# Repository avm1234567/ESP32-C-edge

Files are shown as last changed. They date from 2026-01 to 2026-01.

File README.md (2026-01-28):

<h1 align="center">ESP32-C-edge</h1>

This project is a custom-designed ESP32-S3 development board created by me, featuring a USB Type-C edge connector directly integrated into the PCB. The board is intended to be compact, easy to manufacture, and convenient for prototyping without requiring a separate USB connector footprint.

---

## Overview

- MCU: **ESP32-S3**
- USB Interface: **USB Type-C via PCB edge connector**
- Purpose:
  - Minimal and compact ESP32-S3 dev board  
  - Direct USB connection without soldered connector  
  - Useful for experiments, prototypes, and small form-factor designs  
  - Learning project for PCB edge connectors and USB-C implementation  

---

## Features

- USB Type-C edge connector
- On-board ESP32-S3
- There are 3 USB Type-C in this design
    - Two on the right side are connected to a USB-TTL (CP2102).
    - One on the left is connected to D+ and D- pins of ESP32-S3.

---

## Results
| 3D-Viewer | Actual |
| --- | --- |
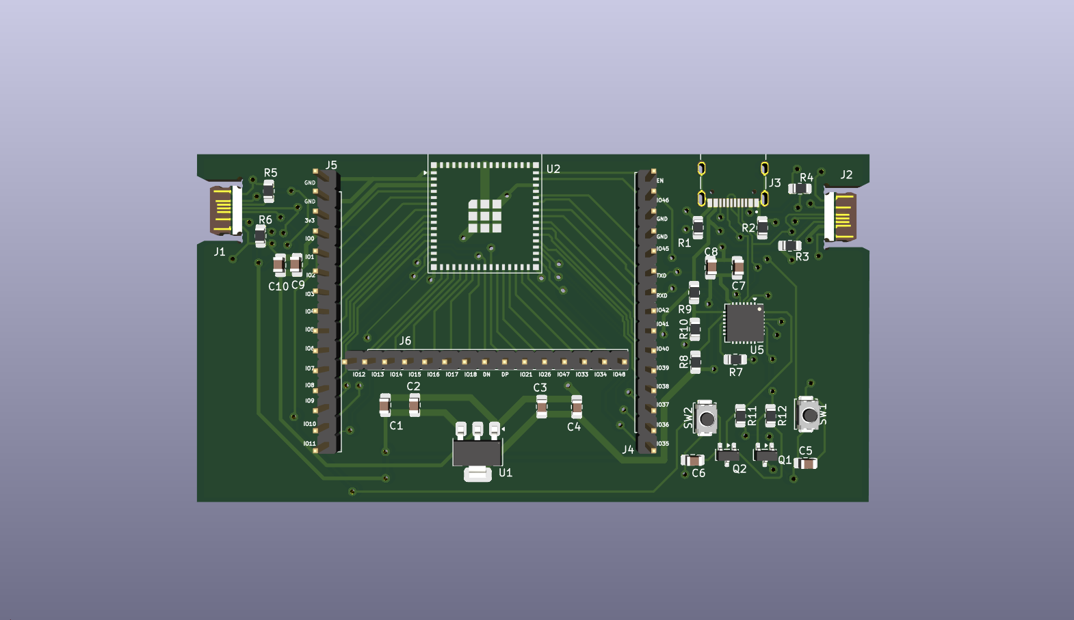
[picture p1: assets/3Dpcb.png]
3D
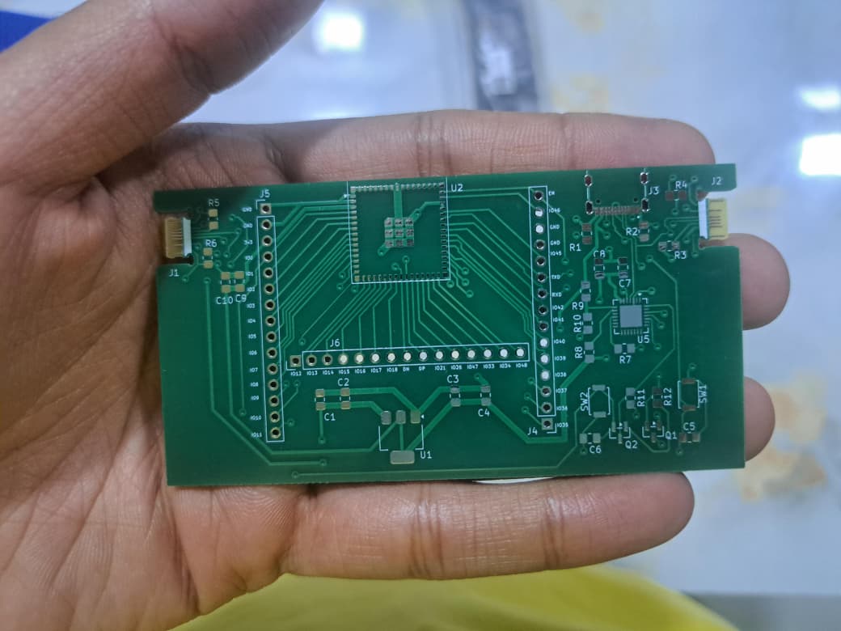
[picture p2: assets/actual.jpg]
Actual
|  |  |

---

## Tools Used

- PCB Design Software: KiCad
- MCU: ESP32-S3
- Fabrication: [JLCPCB](https://jlcpcb.com/)
- PCB-Thickness: 0.6 mm

---

## Future Work

- Improve the silkscreen of PCB.
- Change the corners of PCB.
- Try with 0.8 mm PCB thickness.

---

## Acknowledgement

Special thanks to [AnasMalas](https://github.com/AnasMalas) for publishing the USB Type-C edge connector design which made this project possible and [SRA-VJTI](https://github.com/SRA-VJTI) for providing the components, technical guidance, and hands-on support during the PCB design and development process.

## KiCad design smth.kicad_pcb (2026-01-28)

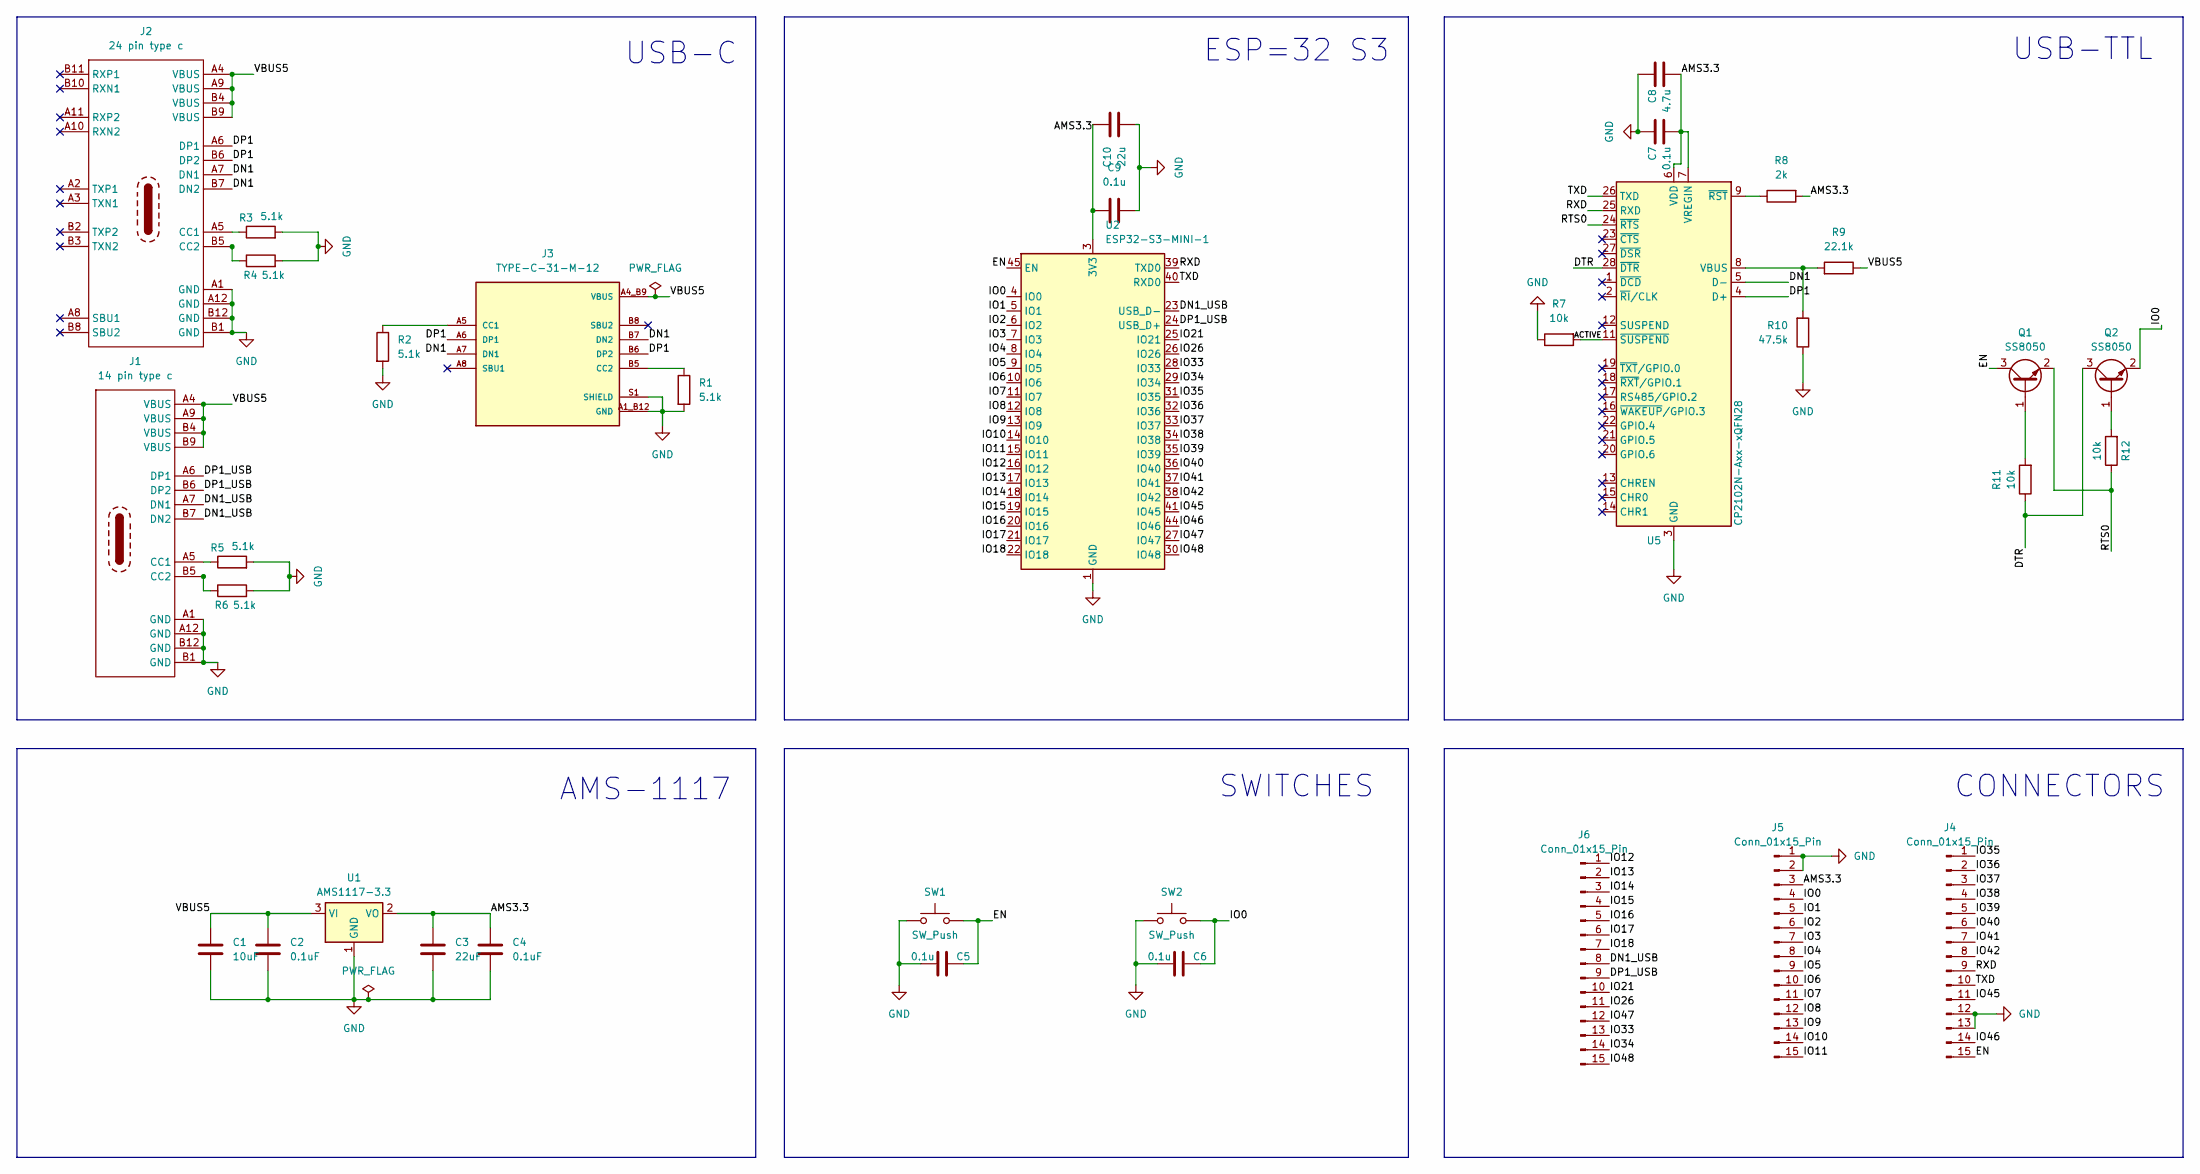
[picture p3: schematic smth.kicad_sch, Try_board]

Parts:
C1: 10uF; C_0805_2012Metric_Pad1.18x1.45mm_HandSolder
C2, C4: 0.1uF; C_0805_2012Metric_Pad1.18x1.45mm_HandSolder
C3: 22uF; C_0805_2012Metric_Pad1.18x1.45mm_HandSolder
C5, C6, C7, C9: 0.1u; C_0805_2012Metric_Pad1.18x1.45mm_HandSolder
C8: 4.7u; C_0805_2012Metric_Pad1.18x1.45mm_HandSolder
C10: 22u; C_0805_2012Metric_Pad1.18x1.45mm_HandSolder
J1: 14 pin type c; PCBTypeC_14P
J2: 24 pin type c; PCBTypeC_14P
J3: TYPE-C-31-M-12; HRO_TYPE-C-31-M-12; PARTREV 2020.12.08
J4, J5, J6: Conn_01x15_Pin; PinHeader_1x14_P2.54mm_Vertical
Q1, Q2: SS8050; SOT-23
R1, R2, R3, R4, R5, R6: 5.1k; R_0805_2012Metric_Pad1.20x1.40mm_HandSolder
R7, R11, R12: 10k; R_0805_2012Metric_Pad1.20x1.40mm_HandSolder
R8: 2k; R_0805_2012Metric_Pad1.20x1.40mm_HandSolder
R9: 22.1k; R_0805_2012Metric_Pad1.20x1.40mm_HandSolder
R10: 47.5k; R_0805_2012Metric_Pad1.20x1.40mm_HandSolder
SW1, SW2: SW_Push; SW_Push_SPST_NO_Alps_SKRK
U1: AMS1117-3.3; SOT-223-3_TabPin2
U2: ESP32-S3-MINI-1; ESP32-S2-MINI-1
U5: CP2102N-Axx-xQFN28; QFN-28-1EP_5x5mm_P0.5mm_EP3.35x3.35mm

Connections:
/ACTIVE: R7.2, U5.11 (~SUSPEND)
/AMS3.3: C3.1, C4.1, C7.2, C8.2, C9.1, C10.1, J5.3, R8.2, U1.2 (VO), U2.3 (3V3), U5.6 (VDD), U5.7 (VREGIN)
/DN1: J2.A7 (DN1), J2.B7 (DN2), J3.A7 (DN1), J3.B7 (DN2), U5.5 (D-)
/DN1_USB: J1.A7 (DN1), J1.B7 (DN2), J6.8, U2.23 (USB_D-)
/DP1: J2.A6 (DP1), J2.B6 (DP2), J3.A6 (DP1), J3.B6 (DP2), U5.4 (D+)
/DP1_USB: J1.A6 (DP1), J1.B6 (DP2), J6.9, U2.24 (USB_D+)
/DTR: Q2.3 (C), R11.1, U5.28 (~DTR)
/EN: C5.1, J4.15, Q1.3 (C), SW1.2, U2.45 (EN)
/IO0: C6.1, J5.4, Q2.2 (E), SW2.2, U2.4 (IO0)
/IO1: J5.5, U2.5 (IO1)
/IO2: J5.6, U2.6 (IO2)
/IO3: J5.7, U2.7 (IO3)
/IO4: J5.8, U2.8 (IO4)
/IO5: J5.9, U2.9 (IO5)
/IO6: J5.10, U2.10 (IO6)
/IO7: J5.11, U2.11 (IO7)
/IO8: J5.12, U2.12 (IO8)
/IO9: J5.13, U2.13 (IO9)
/IO10: J5.14, U2.14 (IO10)
/IO11: J5.15, U2.15 (IO11)
/IO12: J6.1, U2.16 (IO12)
/IO13: J6.2, U2.17 (IO13)
/IO14: J6.3, U2.18 (IO14)
/IO15: J6.4, U2.19 (IO15)
/IO16: J6.5, U2.20 (IO16)
/IO17: J6.6, U2.21 (IO17)
/IO18: J6.7, U2.22 (IO18)
/IO21: J6.10, U2.25 (IO21)
/IO26: J6.11, U2.26 (IO26)
/IO33: J6.13, U2.28 (IO33)
/IO34: J6.14, U2.29 (IO34)
/IO35: J4.1, U2.31 (IO35)
/IO36: J4.2, U2.32 (IO36)
/IO37: J4.3, U2.33 (IO37)
/IO38: J4.4, U2.34 (IO38)
/IO39: J4.5, U2.35 (IO39)
/IO40: J4.6, U2.36 (IO40)
/IO41: J4.7, U2.37 (IO41)
/IO42: J4.8, U2.38 (IO42)
/IO45: J4.11, U2.41 (IO45)
/IO46: J4.14, U2.44 (IO46)
/IO47: J6.12, U2.27 (IO47)
/IO48: J6.15, U2.30 (IO48)
/RTS0: Q1.2 (E), R12.1, U5.24 (~RTS)
/RXD: J4.9, U2.39 (TXD0), U5.25 (RXD)
/TXD: J4.10, U2.40 (RXD0), U5.26 (TXD)
GND: C1.2, C2.2, C3.2, C4.2, C5.2, C6.2, C7.1, C8.1, C9.2, C10.2, J1.A1 (GND), J1.A12 (GND), J1.B1 (GND), J1.B12 (GND), J2.A1 (GND), J2.A12 (GND), J2.B1 (GND), J2.B12 (GND), J3.A1_B12 (GND), J3.B1_A12 (GND), J3.S1 (SHIELD), J3.S2 (SHIELD), J3.S3 (SHIELD), J3.S4 (SHIELD), J4.12, J4.13, J5.1, J5.2, R1.2, R2.2, R3.2, R4.2, R5.2, R6.2, R7.1, R10.1, SW1.1, SW2.1, U1.1 (GND), U2.1 (GND), U2.2 (GND), U2.42 (GND), U2.43 (GND), U2.46 (GND), U2.47 (GND), U2.48 (GND), U2.49 (GND), U2.50 (GND), U2.51 (GND), U2.52 (GND), U2.53 (GND), U2.54 (GND), U2.55 (GND), U2.56 (GND), U2.57 (GND), U2.58 (GND), U2.59 (GND), U2.60 (GND), U2.61 (GND), U2.62 (GND), U2.63 (GND), U2.64 (GND), U2.65 (GND), U5.3 (GND), U5.29 (GND)
unnamed: J1.A5 (CC1), R5.1
unnamed: J1.B5 (CC2), R6.1
unnamed: J2.A5 (CC1), R3.1
unnamed: J2.B5 (CC2), R4.1
unnamed: J3.A5 (CC1), R2.1
unnamed: J3.B5 (CC2), R1.1
unnamed: Q1.1 (B), R11.2
unnamed: Q2.1 (B), R12.2
unnamed: R9.2, R10.2, U5.8 (VBUS)
unnamed: R8.1, U5.9 (~RST)
VBUS: C1.1, C2.1, J1.A4 (VBUS), J1.A9 (VBUS), J1.B4 (VBUS), J1.B9 (VBUS), J2.A4 (VBUS), J2.A9 (VBUS), J2.B4 (VBUS), J2.B9 (VBUS), J3.A4_B9 (VBUS), J3.B4_A9 (VBUS), R9.1, U1.3 (VI)

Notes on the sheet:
SWITCHES
ESP=32 S3
CONNECTORS
USB-C
AMS-1117
USB-TTL

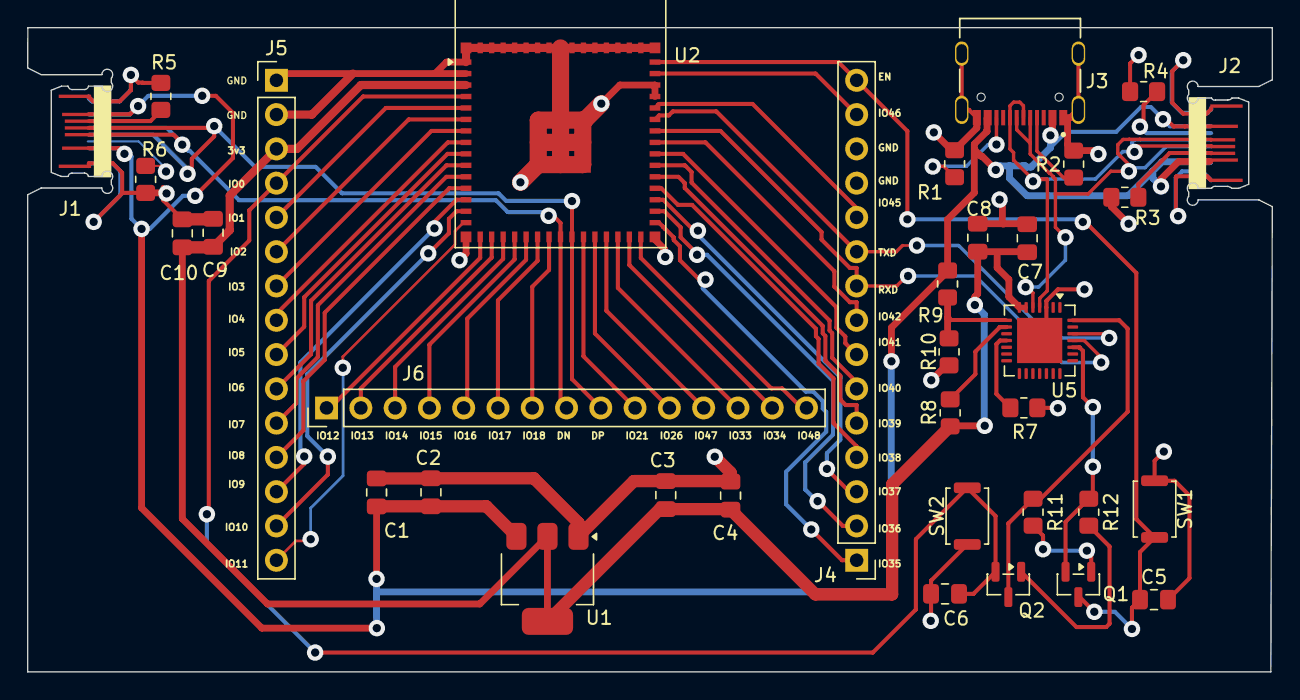
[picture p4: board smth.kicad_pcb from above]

Board: 2 copper layers, 92.2 x 47.7 mm, 35 parts (0 on the bottom side), 58 nets.
